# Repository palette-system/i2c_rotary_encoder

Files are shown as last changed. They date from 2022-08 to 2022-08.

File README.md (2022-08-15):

# I2C ロータリーエンコーダ

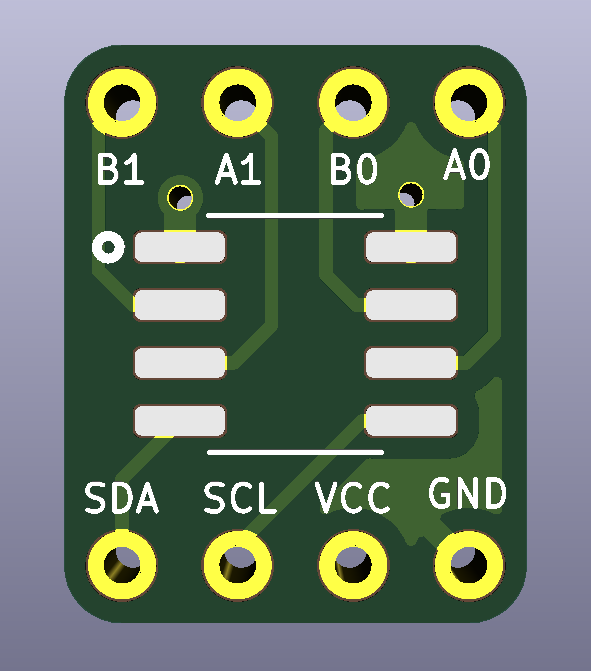
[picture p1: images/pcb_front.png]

<br><br><br>

## 説明

I2CロータリエンコーダはATTiny202を利用したロータリエンコーダの操作をI2C越しに読み込みをするための基板です。<br>
(販売はDIP変換基板と、下記ファームウェアを書き込んだATTiny202を販売します)<br>
<br>

ファームウェアソース<br>
<a href="https://github.com/palette-system/i2c_rotary_encoder/edit/main/software/i2c_rotary_encorder/i2c_rotary_encorder.ino" target="_blank">software/i2c_rotary_encorder/i2c_rotary_encorder.ino</a>

<br><br>

## ATTiny202 ピン

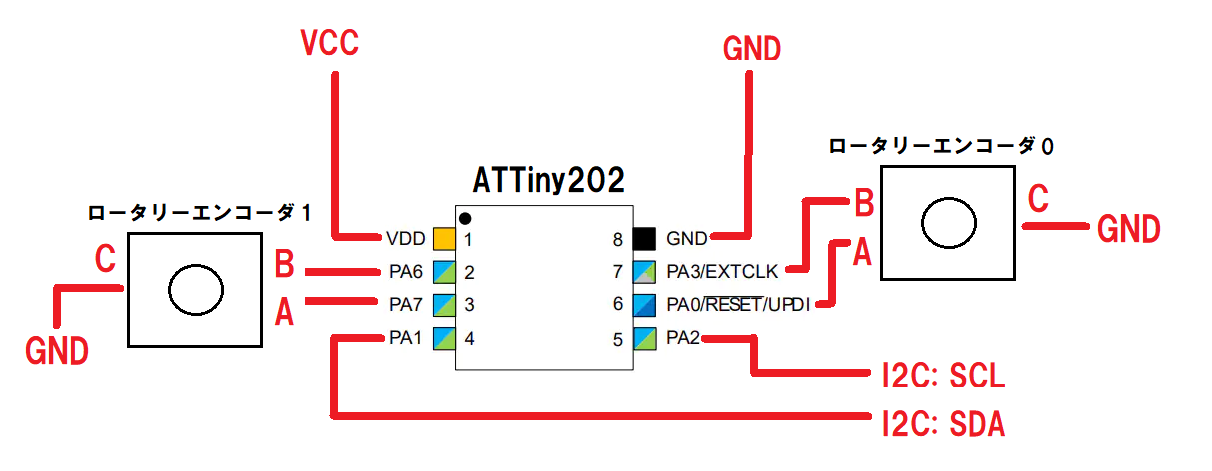
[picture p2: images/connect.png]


<table>
  <tr>
    <th>番号</th>
    <th>ピン</th>
    <th>接続</th>
    <td rowspan="5">　</td>
    <th>番号</th>
    <th>ピン</th>
    <th>接続</th>
  </tr>
  <tr>
    <td>1</td>
    <td>VDD</td>
    <td>VCC</td>
    <td>8</td>
    <td>GND</td>
    <td>GND</td>
  </tr>
  <tr>
    <td>2</td>
    <td>PA6</td>
    <td>rotary1_B</td>
    <td>7</td>
    <td>PA3</td>
    <td>rotary0_B</td>
  </tr>
  <tr>
    <td>3</td>
    <td>PA7</td>
    <td>rotary1_A</td>
    <td>6</td>
    <td>PA0</td>
    <td>rotary0_A</td>
  </tr>
  <tr>
    <td>4</td>
    <td>PA1</td>
    <td>I2C SDA</td>
    <td>5</td>
    <td>PA2</td>
    <td>I2C SCL</td>
  </tr>
</table>
<br><br>

## アドレス設定方法

プログラムの中に固定値でアドレスを指定しているため、ビルドして書込みを行わない限りアドレスの変更はできません。<br>
デフォルトで 0x45 が書き込まれています。<br>
<br><br>

## メリット、デメリット
■　メリット<br>
　・マイコンのI/Oを消費しない<br>
　・アドレス変えていけば割といっぱい付けられる<br>
<br>
■　デメリット<br>
　・実装するICと消費電力が増える<br>
　<br><br>

## 読み込み方
I2Cでアドレスを指定して1バイトリクエストするだけで取得できます。<br>
最後にデータ取得した時から現在までにロータリエンコーダの操作があった場合に該当のビットが１になって帰ってきます。<br>
一度取得するとまた０になり、ロータリエンコーダが操作されるまで０を取得します。<br>
```
  uint8_t r;
  Wire.requestFrom(0x45, 1); // 指定したアドレスのATTiny202に1バイト分データ取得要求
  r = Wire.read(); // 1バイトデータ受け取る
  if (r & 0x08) # ロータリエンコーダ０左回り
  if (r & 0x04) # ロータリエンコーダ０右回り
  if (r & 0x02) # ロータリエンコーダ１左回り
  if (r & 0x01) # ロータリエンコーダ１右回り
```
　<br><br>

## AZ-CORE、えむごっち等に接続する場合のAZTOOL手順

https://twitter.com/4py1/status/1559090793159458816
https://twitter.com/4py1/status/1559088312589365248

## ATTiny202 開発環境の作り方

<a href="https://ameblo.jp/pta55/entry-12654450554.html" target="_blank">https://ameblo.jp/pta55/entry-12654450554.html</a>
<br><br>

## 詳細情報

電圧：　1.8V　～　5.5V  
信号：　I2C　（～1.7MHz）
<br><br>

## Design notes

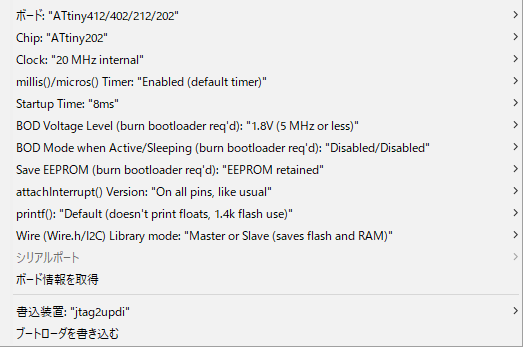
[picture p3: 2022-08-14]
images/board.png

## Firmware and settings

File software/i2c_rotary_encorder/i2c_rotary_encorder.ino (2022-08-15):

// ロータリーエンコーダーの入力をI2Cに流す

// 開発環境の作り方
// https://ameblo.jp/pta55/entry-12654450554.html

#include <Wire.h>
#include <avr/pgmspace.h> 

// ATTiny202 本体のアドレス
#define I2C_SLAVE_ADD 0x45

uint8_t key_input = 0x00;
uint8_t old_input = 0x00;
uint8_t send_input = 0x00;

// I2Cデータ要求を受け取った時の処理
void requestEvent();

void setup() {
    // ロータリーエンコーダ読み込みピンの初期化
    pinMode(A7, INPUT_PULLUP);
    pinMode(A6, INPUT_PULLUP);
    pinMode(A0, INPUT_PULLUP);
    pinMode(A3, INPUT_PULLUP);
  
    // I2C スレーブ初期化
    Wire.begin(I2C_SLAVE_ADD);
    Wire.onRequest(requestEvent);

}

// I2Cデータ要求を受け取った時の処理
void requestEvent() {
    Wire.write(send_input);
    send_input = 0x00;
}

void loop() {
  // key read
  old_input = key_input;

  // 今回分を読み取り
  key_input = 0x00;
  if (digitalRead(A6)) key_input |= 0x01;
  if (digitalRead(A7)) key_input |= 0x02;
  if (digitalRead(A0)) key_input |= 0x04;
  if (digitalRead(A3)) key_input |= 0x08;

  // ロータリーエンコーダー０
  if ((old_input & 0x03) == 0x03) { // 前の読み取りが AB両方ONだった
      if ((key_input & 0x01) && !(key_input & 0x02)) { // 今回Aのみ
          send_input |= 0x01;
      } else if (!(key_input & 0x01) && (key_input & 0x02)) { // 今回Bのみ
          send_input |= 0x02;
      }
  }

  // ロータリーエンコーダー１
  if ((old_input & 0x0c) == 0x0c) { // 前の読み取りが AB両方ONだった
      if ((key_input & 0x04) && !(key_input & 0x08)) { // 今回Aのみ
          send_input |= 0x04;
      } else if (!(key_input & 0x04) && (key_input & 0x08)) { // 今回Bのみ
          send_input |= 0x08;
      }
  }

  delay(2);
}
